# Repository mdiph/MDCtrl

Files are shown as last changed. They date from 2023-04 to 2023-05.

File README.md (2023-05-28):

# MDCtrl
DIY simple and ultraportable controller powered by [GP2040-CE Firmware](https://github.com/OpenStickCommunity/GP2040-CE)

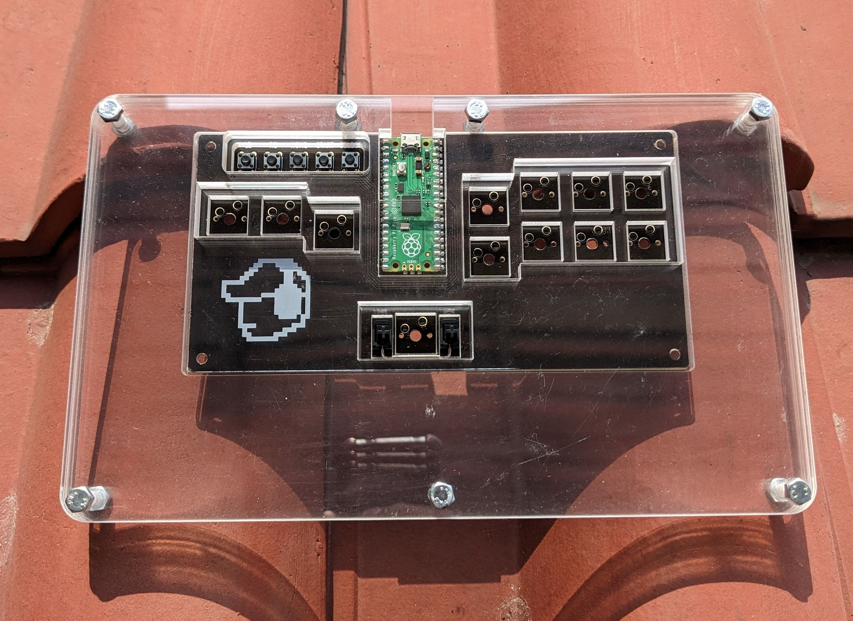
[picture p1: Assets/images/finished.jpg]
Finished MDCtrl

---

# BOM

The component that you need to build MDCtrl:
- MDCtrl [PCB](/Ver1/pcb/)
- MDCtrl Case [(2D)](/Case/)
- Raspberry Pi Pico 
- **12** Kailh hotswap sockets (Optional)
- **12** Keyboard switches
- **12** Keycaps
- **1** Stabilizer
- **5** 6x6x5 [Tactile Switches](https://www.hdk.co.jp/pdf/eng/e291702.pdf)
- Soldering component
- Rubber Feet (For the bottom of the case)

PCB thickness should be 1,6mm (Double layer) with masking color of your choice

# Board

Board Version |   [Ver1](/Ver1/)  |  [Ver2 (WIP)](/Ver2/)  |
--------------|:-----------------:|:----------------:|
PCB Dimension | 175,418x87,312mm  | WIP              |
Board Used    | [Raspberry Pi Pico](https://www.raspberrypi.com/products/raspberry-pi-pico/) | [Waveshare RP2040-Zero](https://www.waveshare.com/rp2040-zero.htm)|
Port          | Micro USB         | USB-C            |

# Sources

PCB Design built with the following sources:
- [Firmware GP2040-CE](https://github.com/OpenStickCommunity/GP2040-CE)
- [Raspberry Pi Pico Footprint by Nicolò Carandini](https://github.com/ncarandini/KiCad-RP-Pico)
- [Keyboard Switches Footprint](https://github.com/ebastler/marbastlib)

---

Shield: [][cc-by-sa]

This work is licensed under a
[Creative Commons Attribution-ShareAlike 4.0 International License][cc-by-sa].

[][cc-by-sa]

[cc-by-sa]: http://creativecommons.org/licenses/by-sa/4.0/
[cc-by-sa-image]: https://licensebuttons.net/l/by-sa/4.0/88x31.png
[cc-by-sa-shield]: https://img.shields.io/badge/License-CC%20BY--SA%204.0-lightgrey.svg

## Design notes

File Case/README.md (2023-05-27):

# Case Install Guide (For ver1)

## **Case Components**
---
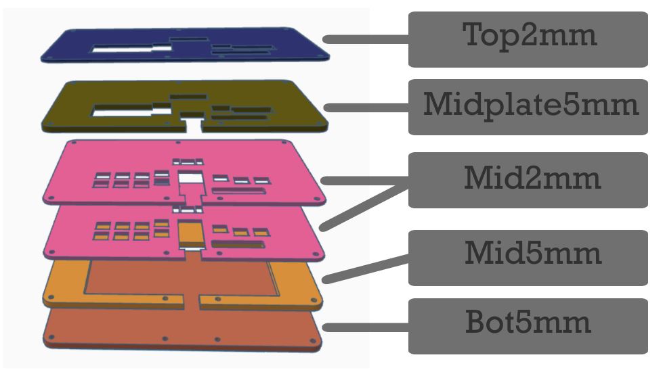
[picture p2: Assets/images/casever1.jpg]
Case Install Guide


---
## **Case Assembly**
Assemble the different case like the provided picture.

There's 2 different thickness for the case:
-   [2mm Case](/Case/Case2D/ver1/2mm/)
-   [5mm Case](/Case/Case2D/ver1/5mm/)

Note: **Ver 1 case uses M5x25 screws**

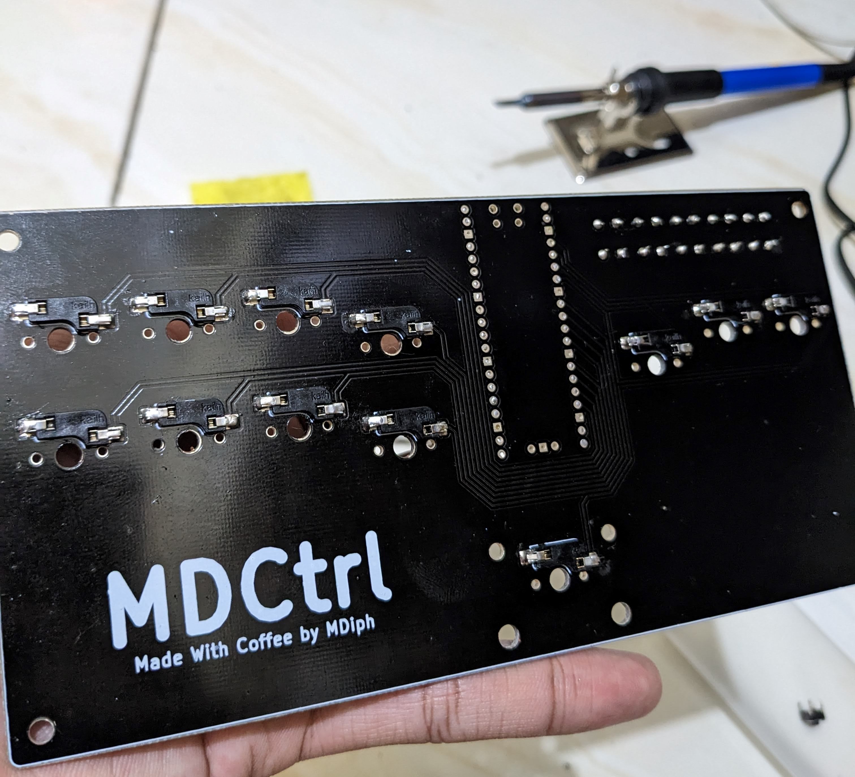
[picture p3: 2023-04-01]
Assets/images/board.jpg

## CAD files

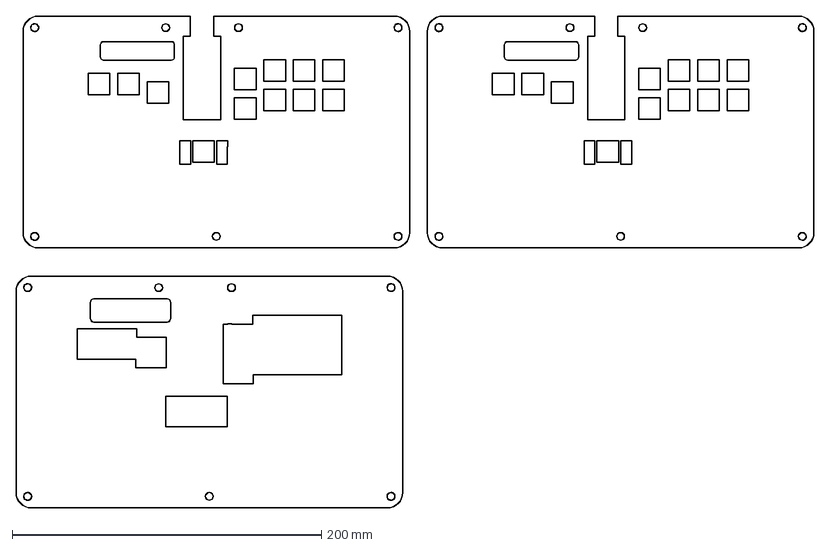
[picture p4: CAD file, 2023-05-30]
Case/Case2D/ver1/2mm/Case2mm.dxf
515.9 x 318.1 mm

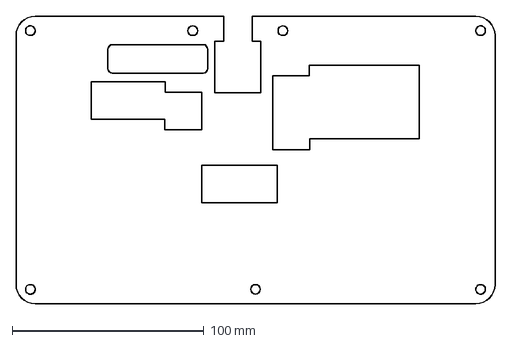
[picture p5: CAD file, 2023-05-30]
Case/Case2D/ver1/5mm/Midplate5mm.dxf
250.0 x 150.0 mm

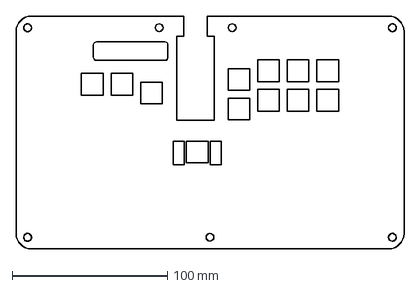
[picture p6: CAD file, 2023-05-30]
Case/Case2D/ver1/2mm/Mid2mm.dxf
250.0 x 150.0 mm

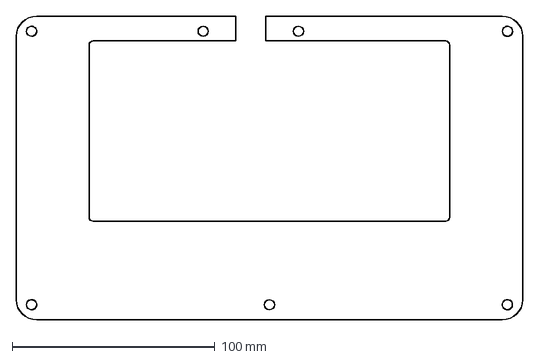
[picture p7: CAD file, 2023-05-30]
Case/Case2D/ver1/5mm/Mid5mm.dxf
250.0 x 150.0 mm

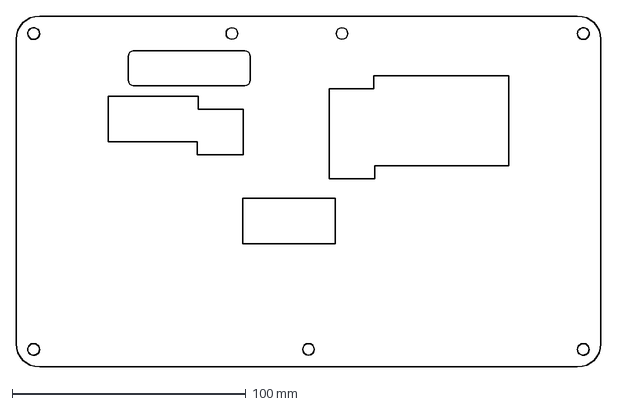
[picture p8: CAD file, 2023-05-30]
Case/Case2D/ver1/2mm/Top2mm.dxf
250.0 x 150.0 mm

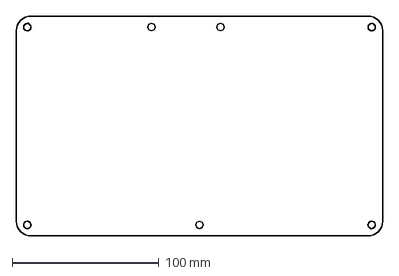
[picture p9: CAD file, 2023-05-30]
Case/Case2D/ver1/5mm/Bot5mm.dxf
250.0 x 150.0 mm

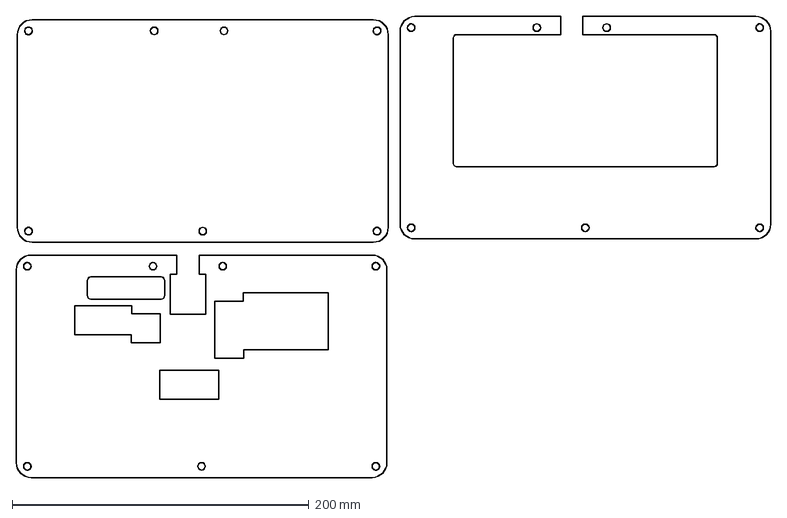
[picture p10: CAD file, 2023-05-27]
Case/Case2D/ver1/5mm/Case5mm.dxf
508.8 x 310.8 mm

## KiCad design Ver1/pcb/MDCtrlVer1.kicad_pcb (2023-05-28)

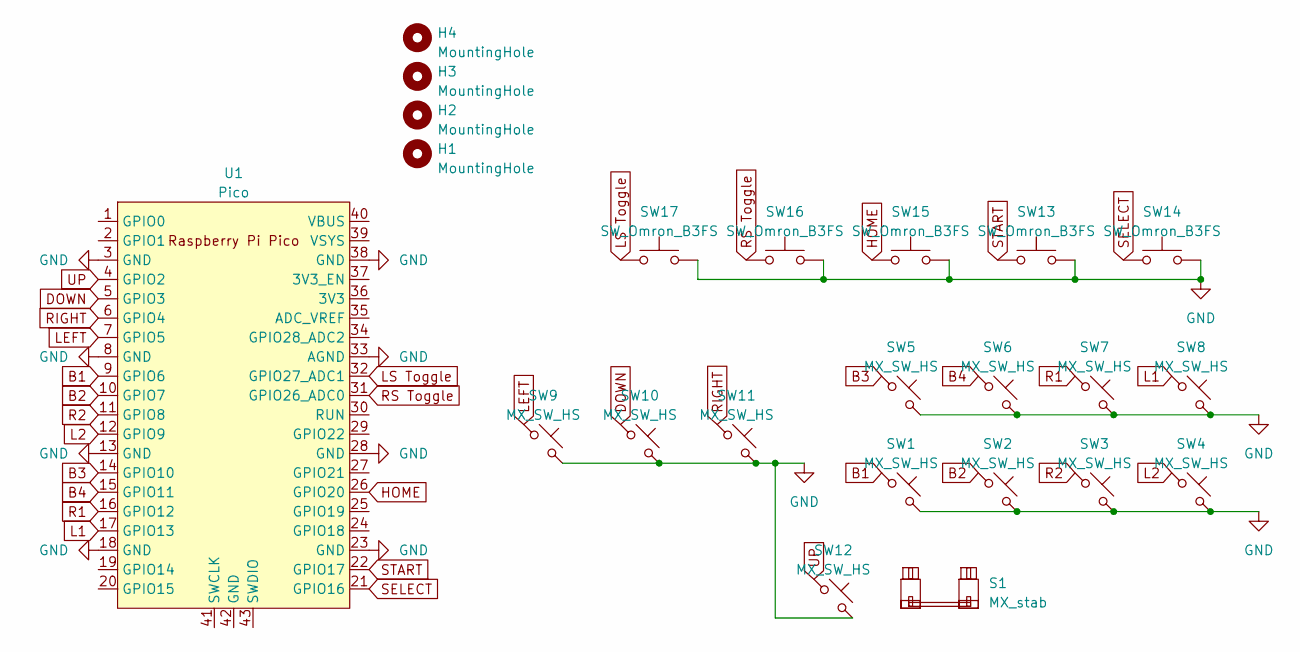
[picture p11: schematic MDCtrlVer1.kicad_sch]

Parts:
H1, H2, H3, H4: MountingHole; MountingHole_3.5mm
S1: MX_stab; STAB_MX_2u
SW1, SW2, SW3, SW4, SW5, SW6, SW7, SW8, SW9, SW10, SW11, SW12: MX_SW_HS; SW_MX_HS_1u
SW13, SW14, SW15, SW16, SW17: SW_Omron_B3FS; SW_PUSH_6mm_H5mm
U1: Pico; RPi_Pico_SMD_TH

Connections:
B1: SW1.1, U1.9 (GPIO6)
B2: SW2.1, U1.10 (GPIO7)
B3: SW5.1, U1.14 (GPIO10)
B4: SW6.1, U1.15 (GPIO11)
DOWN: SW10.1, U1.5 (GPIO3)
GND: SW1.2, SW2.2, SW3.2, SW4.2, SW5.2, SW6.2, SW7.2, SW8.2, SW9.2, SW10.2, SW11.2, SW12.2, SW13.2, SW14.2, SW15.2, SW16.2, SW17.2, U1.3 (GND), U1.8 (GND), U1.13 (GND), U1.18 (GND), U1.23 (GND), U1.28 (GND), U1.33 (AGND), U1.38 (GND)
HOME: SW15.1, U1.26 (GPIO20)
L1: SW8.1, U1.17 (GPIO13)
L2: SW4.1, U1.12 (GPIO9)
LEFT: SW9.1, U1.7 (GPIO5)
LS Toggle: SW17.1, U1.32 (GPIO27_ADC1)
R1: SW7.1, U1.16 (GPIO12)
R2: SW3.1, U1.11 (GPIO8)
RIGHT: SW11.1, U1.6 (GPIO4)
RS Toggle: SW16.1, U1.31 (GPIO26_ADC0)
SELECT: SW14.1, U1.21 (GPIO16)
START: SW13.1, U1.22 (GPIO17)
UP: SW12.1, U1.4 (GPIO2)

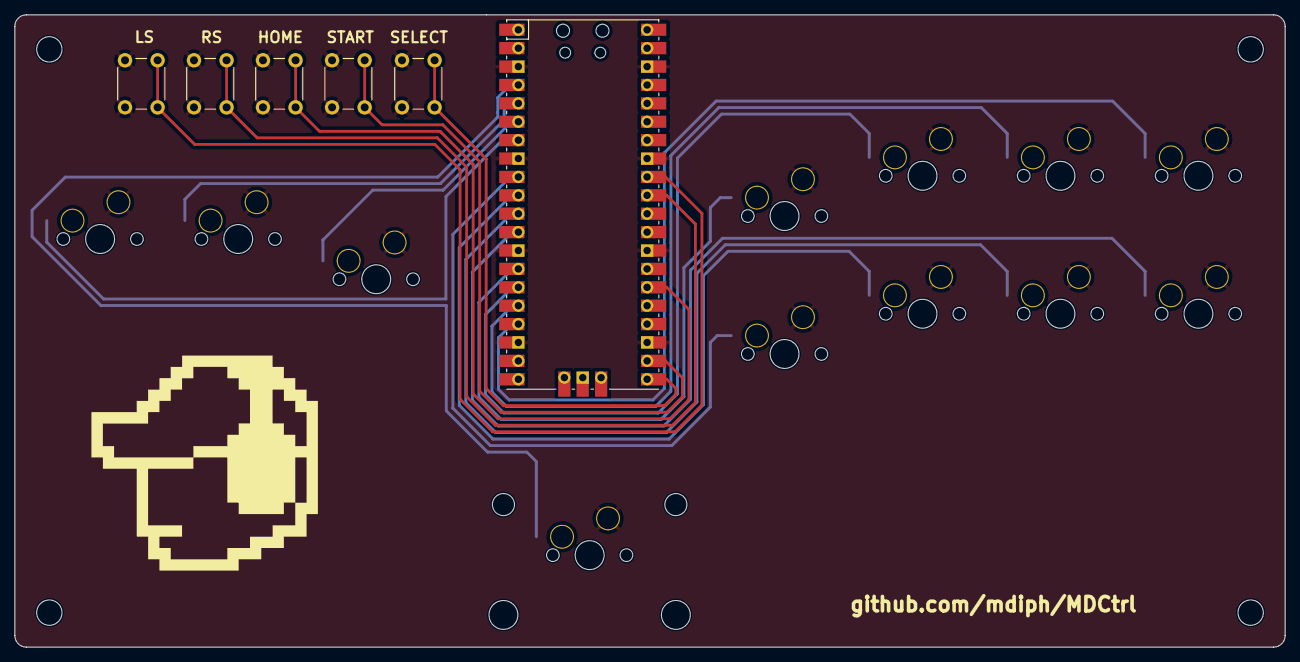
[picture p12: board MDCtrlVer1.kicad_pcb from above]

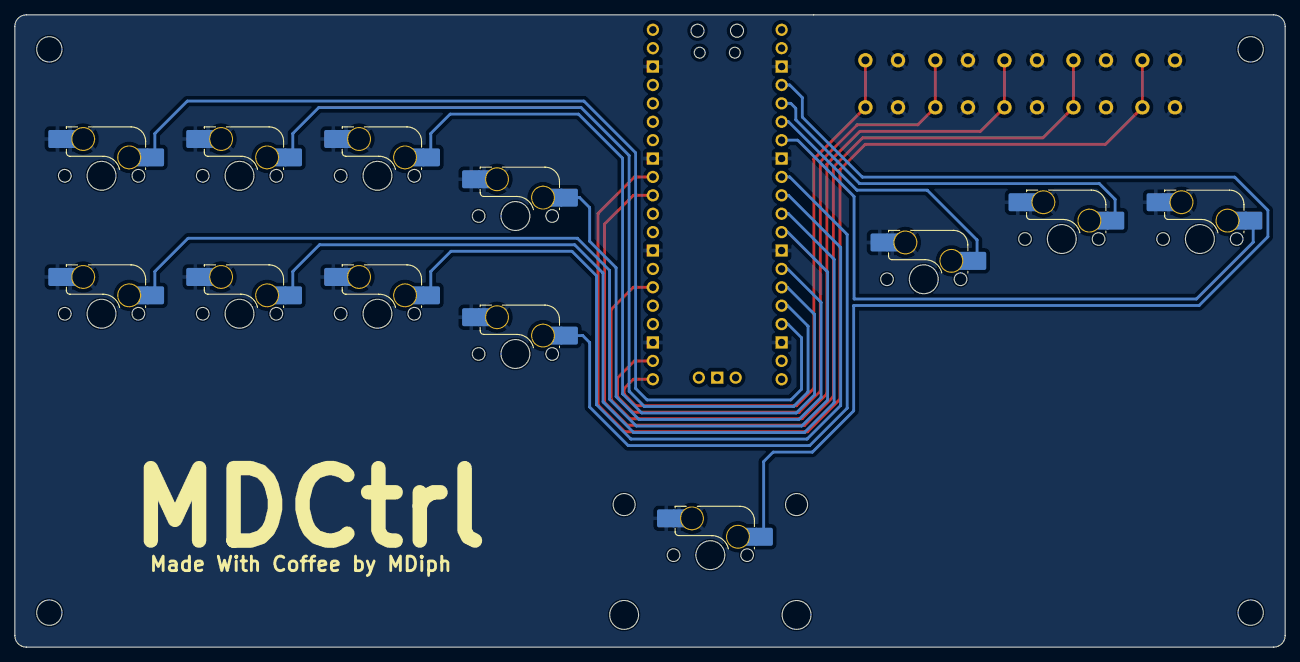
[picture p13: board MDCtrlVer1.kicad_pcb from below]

Board: 2 copper layers, 175.4 x 87.3 mm, 23 parts (12 on the bottom side), 18 nets.

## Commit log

2023-04-01 adding version 1
    [MDCtrlVer1.kicad_pcb, MDCtrlVer1.kicad_sch]
2023-04-01 Added pcb
    [MDCtrlVer1.kicad_pcb, MDCtrlVer1.kicad_sch]
2023-05-27 Updated Case
    [Bot5mm.dxf, Case2mm.dxf, Case5mm.dxf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]
2023-05-27 Fixing stuff
    [Bot5mm.dxf, Case2mm.dxf, Case5mm.dxf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]
2023-05-28 adding minor changes
    [MDCtrlVer1.kicad_pcb]
2023-05-30 Fixing dxf files
    [Bot5mm.dxf, Case2mm.dxf, Mid2mm.dxf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]

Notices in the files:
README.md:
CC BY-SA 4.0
